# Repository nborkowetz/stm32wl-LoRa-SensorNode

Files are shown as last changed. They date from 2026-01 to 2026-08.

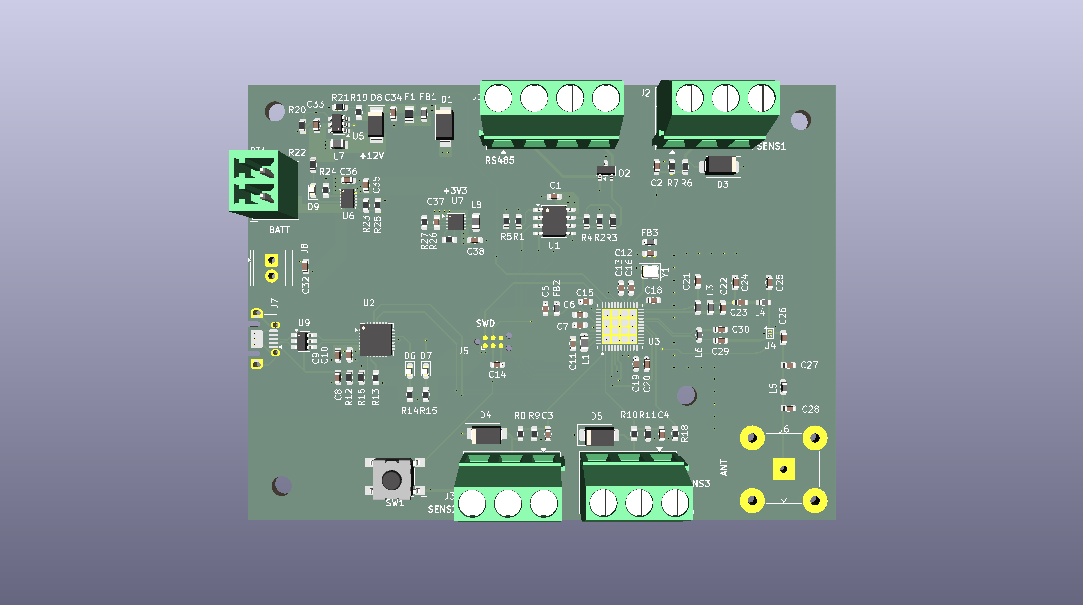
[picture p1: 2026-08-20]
Hardware/pcb/demo wateranalyser.png

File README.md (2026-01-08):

# STM32WL LoRaWAN Prototyping Platform
## Modular Sensor Node for Industrial IoT & Water Quality Monitoring

## 📌 Project Overview
This repository contains the hardware design for a high-performance, ultra-low-power LoRaWAN node based on the **STM32WL55CCU6** SoC. 

This platform serves as an **architectural evaluation board**. It is designed to validate power management strategies, RF performance, and modular sensor interfacing before final product miniaturization.

## 🛠 Technical Specifications

### Core System
* **MCU:** STM32WL55CCU6 (Dual-core ARM Cortex-M4/M0+).
* **Connectivity:** Sub-GHz radio supporting LoRa, (G)FSK, (G)MSK, and BPSK.
* **RF Path:** Optimized 868MHz output with an integrated **BGS12WN6** RF switch and pi-filter matching network.

### Power Management (Ultra-Low Power Focus)
The hardware implements a sophisticated power tree for extreme battery longevity:
* **TPS63900 Buck-Boost:** High-efficiency converter with ultra-low quiescent current, providing a stable 3.3V output across the entire battery discharge curve.
* **LiFePO4 Charging:** Integrated **BQ25071** linear charger, specifically optimized for the safety and cycle-life requirements of LiFePO4 chemistry.
* **Power Gating:** Dedicated load switches to fully disconnect sensor peripherals during deep-sleep cycles, minimizing leakage current.

### PCB Design & Signal Integrity
* **Layer Stack:** 4-layer design (Signal-GND-PWR-Signal) utilizing the **JLC04161H** stackup.
* **Impedance Control:** * **50Ω Single-Ended:** Precision routing for the RF signal path to the antenna.
  * **90Ω Differential:** Calculated for USB data integrity.
* **Manufacturing Ready:** The layout has successfully passed **DFM (Design for Manufacturing)** suites for industrial production standards.

## 🧪 Modular Sensing Interface
To act as a versatile testbed, the board includes:
* Multi-protocol headers (I2C, SPI, UART).
* Analog conditioning circuitry for environmental probes.
* ESD protection on all external sensor interface lines.

## 📂 Project Status
* **Hardware:** Design finalized and DFM-validated. Ready for prototyping.
* **Firmware:** Under active development. Implementing low-power routines and LoRaWAN stack integration using STM32CubeWL HAL.

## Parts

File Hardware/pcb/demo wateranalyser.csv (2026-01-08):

Id | Riferimento | Impronta | Quantità | Valore | Produttore
1 | FB3,FB2 | L_0603_1608Metric | 2 | 600Ohm@10MHz
2 | J1 | TerminalBlock_Phoenix_MKDS-1,5-4-5.08_1x04_P5.08mm_Horizontal | 1 | Screw_Terminal_01x04
3 | R23,R5,R20,R18,R10,R6,R1,R8 | R_0603_1608Metric | 8 | 10k
4 | L8 | L_0805_2012Metric | 1 | 2u2
5 | C32,C37 | C_0603_1608Metric | 2 | 10u
6 | C34,C38,C33 | C_0603_1608Metric | 3 | 22u
7 | R15,R22,R14 | R_0603_1608Metric | 3 | 750
8 | R24 | R_0603_1608Metric | 1 | 1k
9 | C6,C4,C10,C16,C19,C12,C7,C3,C1,C2,C18,C15,C8,C35,C36 | C_0603_1608Metric | 15 | 100n
10 | L7 | L_0805_2012Metric | 1 | 10u
11 | J3,J2,J4 | TerminalBlock_Phoenix_MKDS-1,5-3-5.08_1x03_P5.08mm_Horizontal | 3 | Screw_Terminal_01x03
12 | L1 | L_0805_2012Metric | 1 | 15u
13 | BT1 | PhoenixContact_MCV_1,5_2-G-3.81_1x02_P3.81mm_Vertical | 1 | Battery
14 | R27 | R_0603_1608Metric | 1 | 36k5
15 | D7,D6,D9 | LED_0603_1608Metric | 3 | LED
16 | C14,C13 | C_0603_1608Metric | 2 | 470n
17 | L3 | L_0603_1608Metric | 1 | 6n8
18 | R19 | R_0603_1608Metric | 1 | 41k7
19 | R13,R21 | R_0603_1608Metric | 2 | 2k2
20 | U4 | Infineon_PG-TSNP-6-10_0.7x1.1mm_0.7x1.1mm_P0.4mm | 1 | BGS12WN6E6327
21 | U2 | QFN-28-1EP_5x5mm_P0.5mm_EP3.35x3.35mm | 1 | CP2102N-Axx-xQFN28
22 | R7,R11,R26,R9 | R_0603_1608Metric | 4 | 16k2
23 | D2 | SOT-23 | 1 | SM712_SOT23
24 | D4,D3,D5 | D_SMA | 3 | SMAJ6.0CA
25 | U7 | WSON-10-1EP_2.5x2.5mm_P0.5mm_EP1.2x2mm_ThermalVias | 1 | TPS63900
26 | SW1 | SW_SPST_Omron_B3FS-100xP | 1 | SW_Omron_B3FS
27 | J7 | USB_Micro-AB_Molex_47590-0001 | 1 | USB_B_Micro
28 | R2,R3 | R_0603_1608Metric | 2 | 10
29 | FB1 | L_0603_1608Metric | 1 | 220Ohm @ 100MHz
30 | U5 | SOT-23-6 | 1 | MT3608
31 | C24 | C_0603_1608Metric | 1 | 15p
32 | C11,C20,C9,C5 | C_0603_1608Metric | 4 | 4u7
33 | L2 | L_0603_1608Metric | 1 | 56n
34 | F1 | Fuse_0805_2012Metric | 1 | 200mA
35 | U9 | SOT-23-6_Handsoldering | 1 | WE-TVS-82400102
36 | R4 | R_0603_1608Metric | 1 | 120
37 | C25 | C_0603_1608Metric | 1 | 5p6
38 | C30 | C_0603_1608Metric | 1 | 4p7
39 | L6 | L_0603_1608Metric | 1 | 33n
40 | C26,C23,C21 | C_0603_1608Metric | 3 | 68p
41 | J8 | TerminalBlock_TE_282834-2_1x02_P2.54mm_Horizontal | 1 | Conn_01x02
42 | R12 | R_0603_1608Metric | 1 | 22k1
43 | L4,L5 | L_0603_1608Metric | 2 | 16n
44 | C28,C27 | C_0603_1608Metric | 2 | 6p8
45 | U3 | QFN-48-1EP_7x7mm_P0.5mm_EP5.6x5.6mm | 1 | STM32WL55CCUx
46 | Y1 | Oscillator_SMD_SeikoEpson_SG210-4Pin_2.5x2.0mm | 1 | SG-210STF 32MHz
47 | U1 | SOIC-8_3.9x4.9mm_P1.27mm | 1 | THVD1400D
48 | U6 | WSON-10-1EP_2x3mm_P0.5mm_EP0.84x2.4mm_ThermalVias | 1 | BQ25071
49 | R16 | R_0603_1608Metric | 1 | 47k5
50 | J6 | BNC_TEConnectivity_1478035_Horizontal | 1 | Conn_Coaxial
51 | R25 | R_0603_1608Metric | 1 | 49k
52 | D1 | D_SMA | 1 | SMAJ12CA
53 | C29 | C_0603_1608Metric | 1 | 3p6
54 | C22 | C_0603_1608Metric | 1 | 4p3
55 | D8 | D_SOD-128 | 1 | SB120

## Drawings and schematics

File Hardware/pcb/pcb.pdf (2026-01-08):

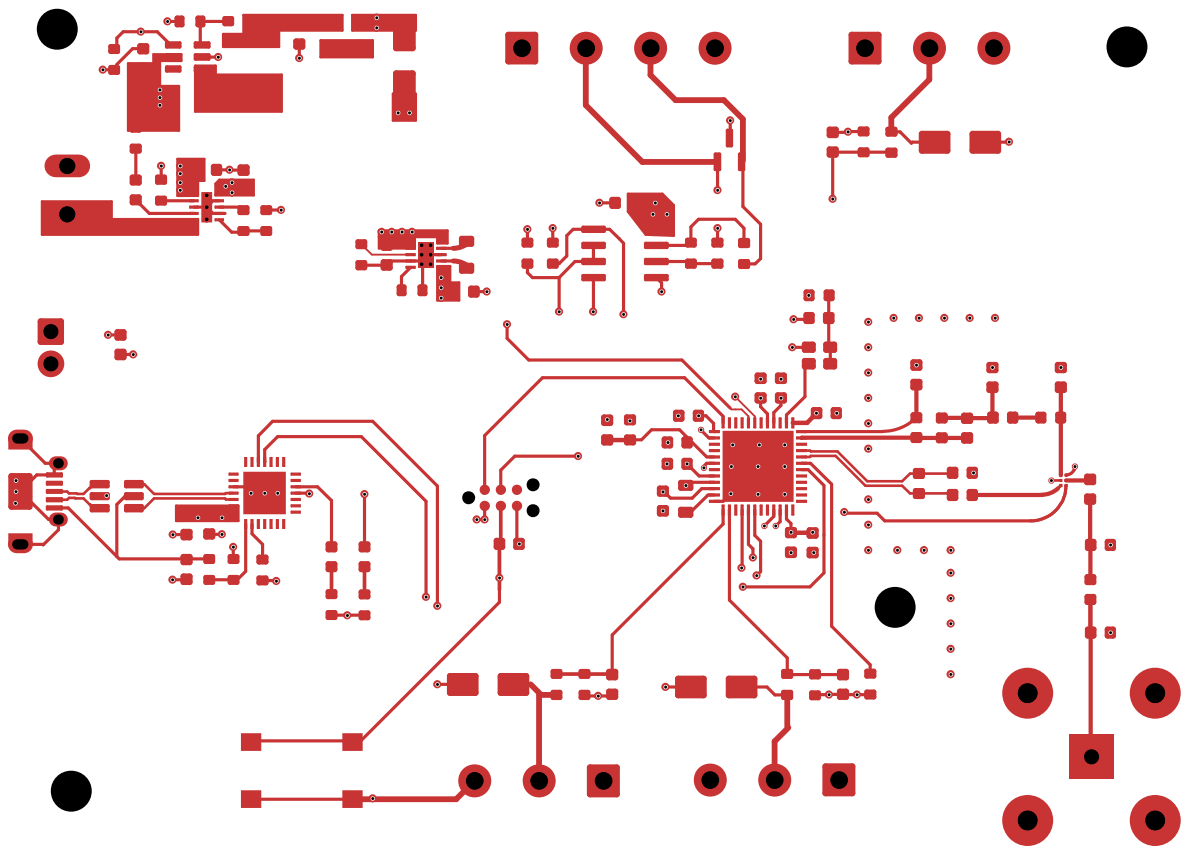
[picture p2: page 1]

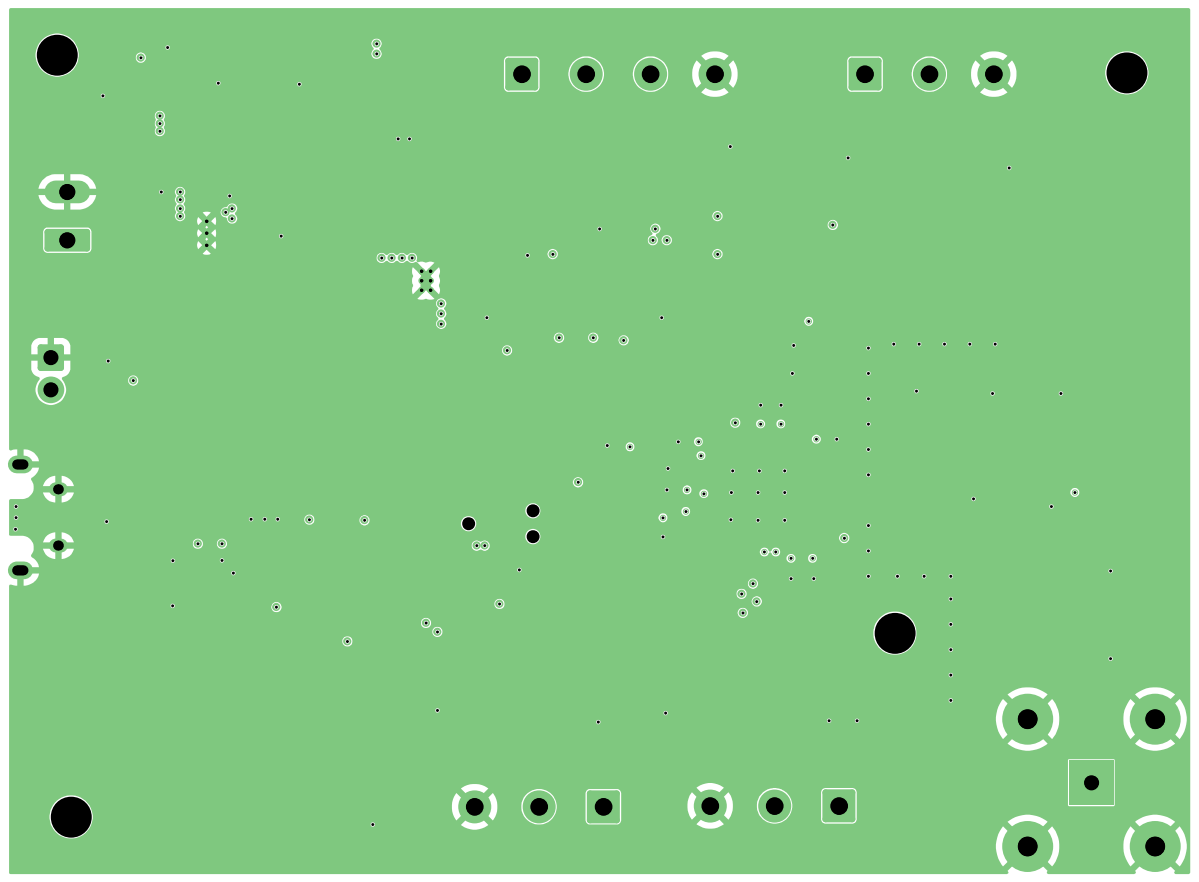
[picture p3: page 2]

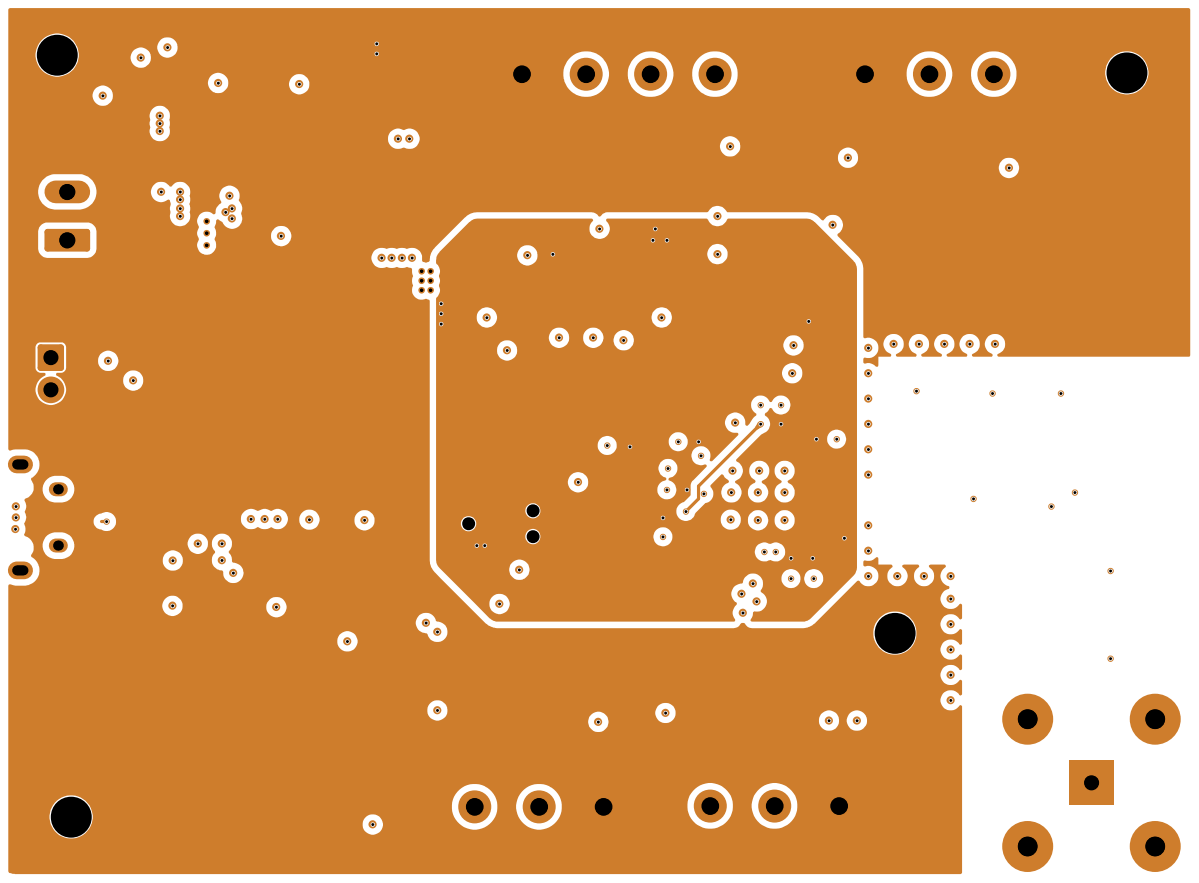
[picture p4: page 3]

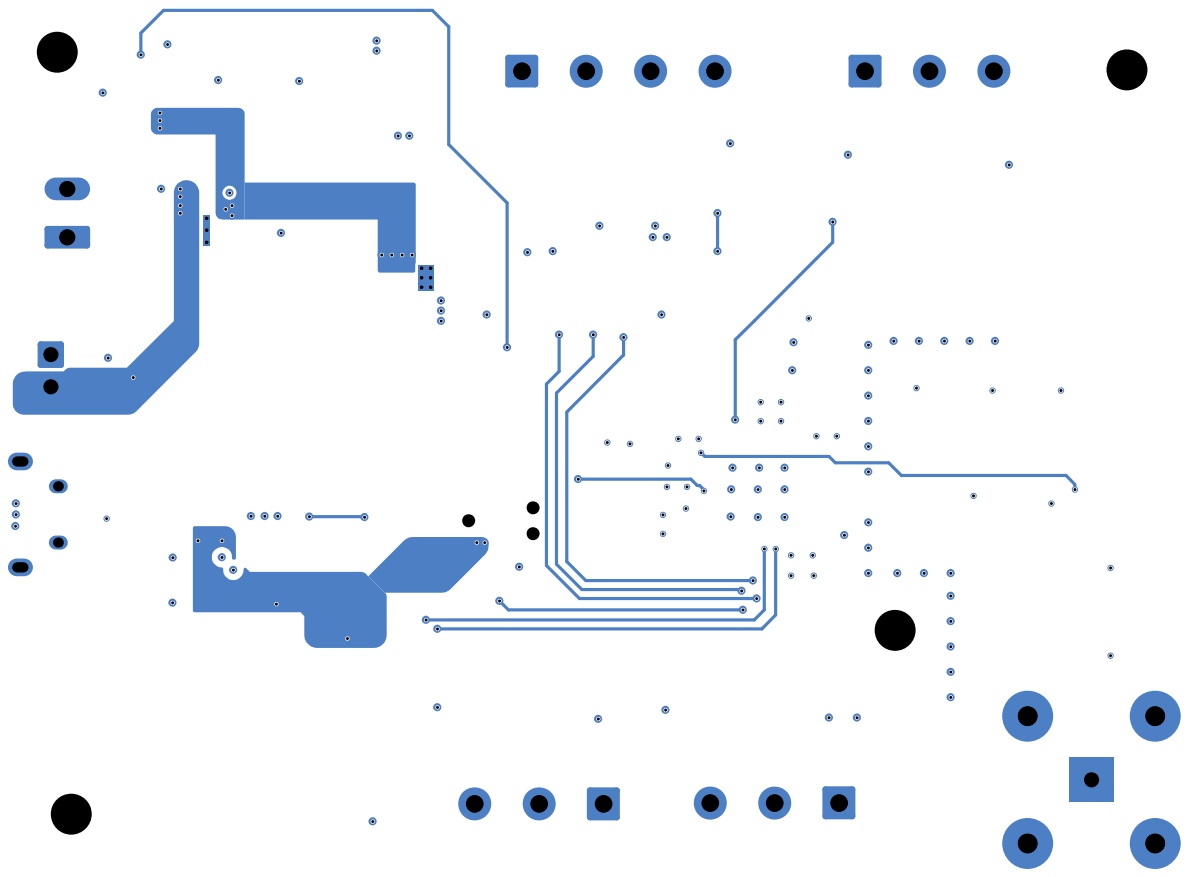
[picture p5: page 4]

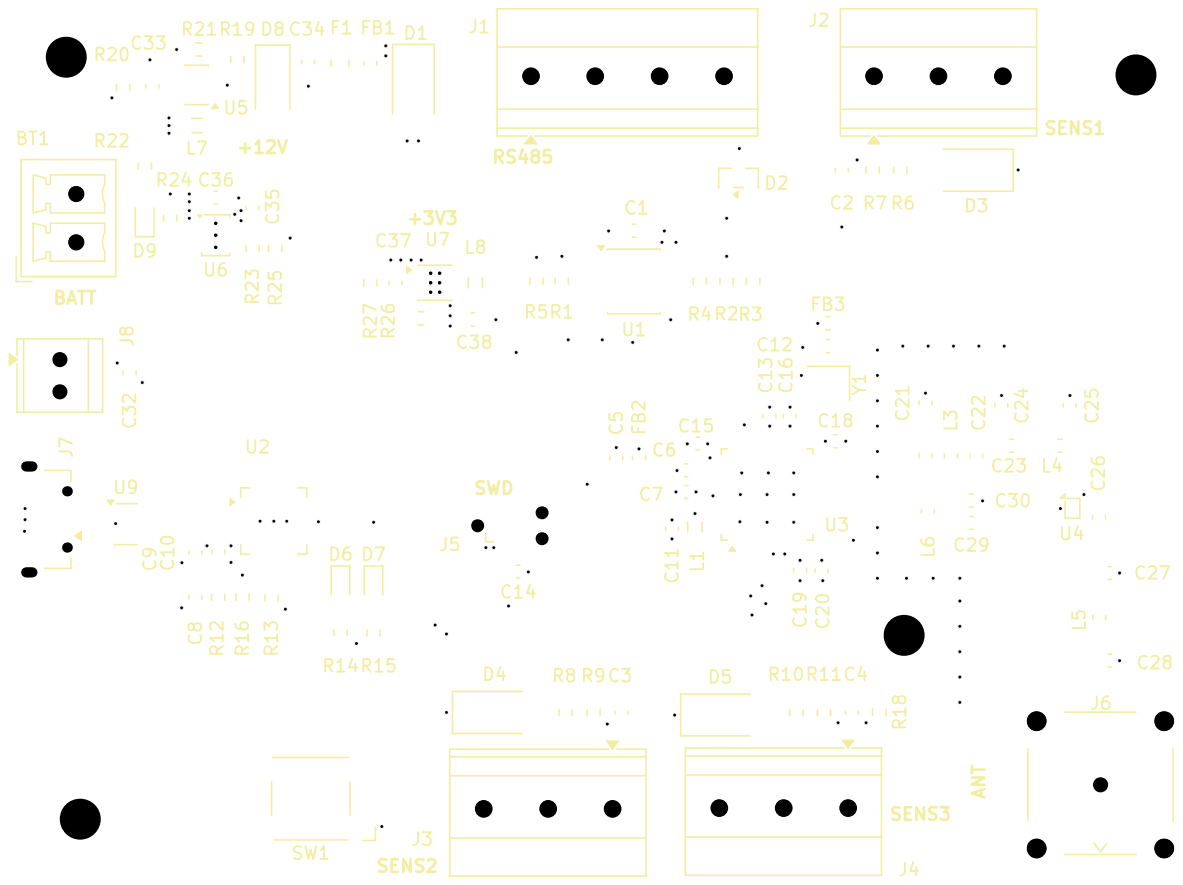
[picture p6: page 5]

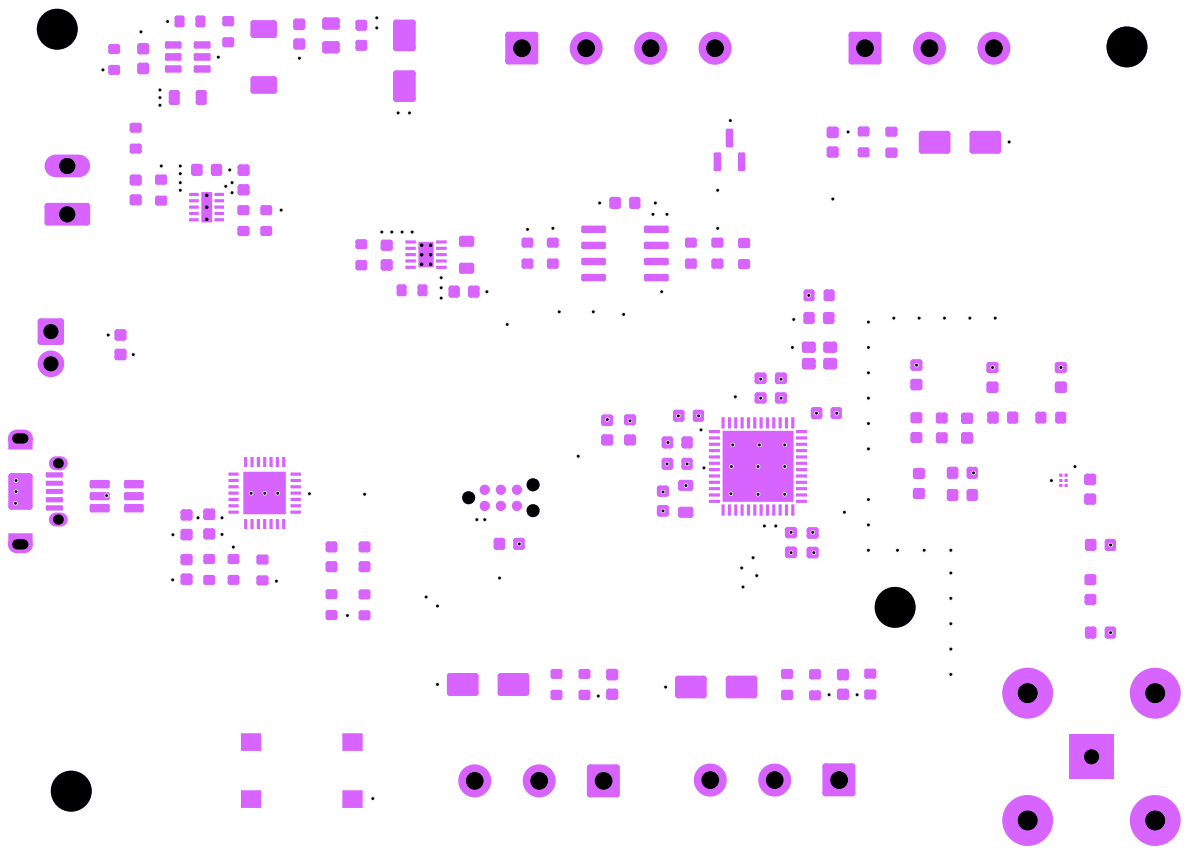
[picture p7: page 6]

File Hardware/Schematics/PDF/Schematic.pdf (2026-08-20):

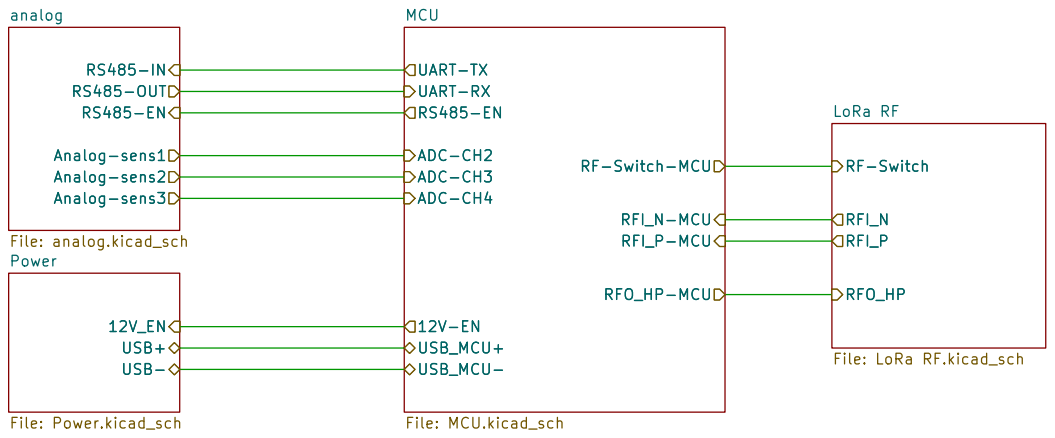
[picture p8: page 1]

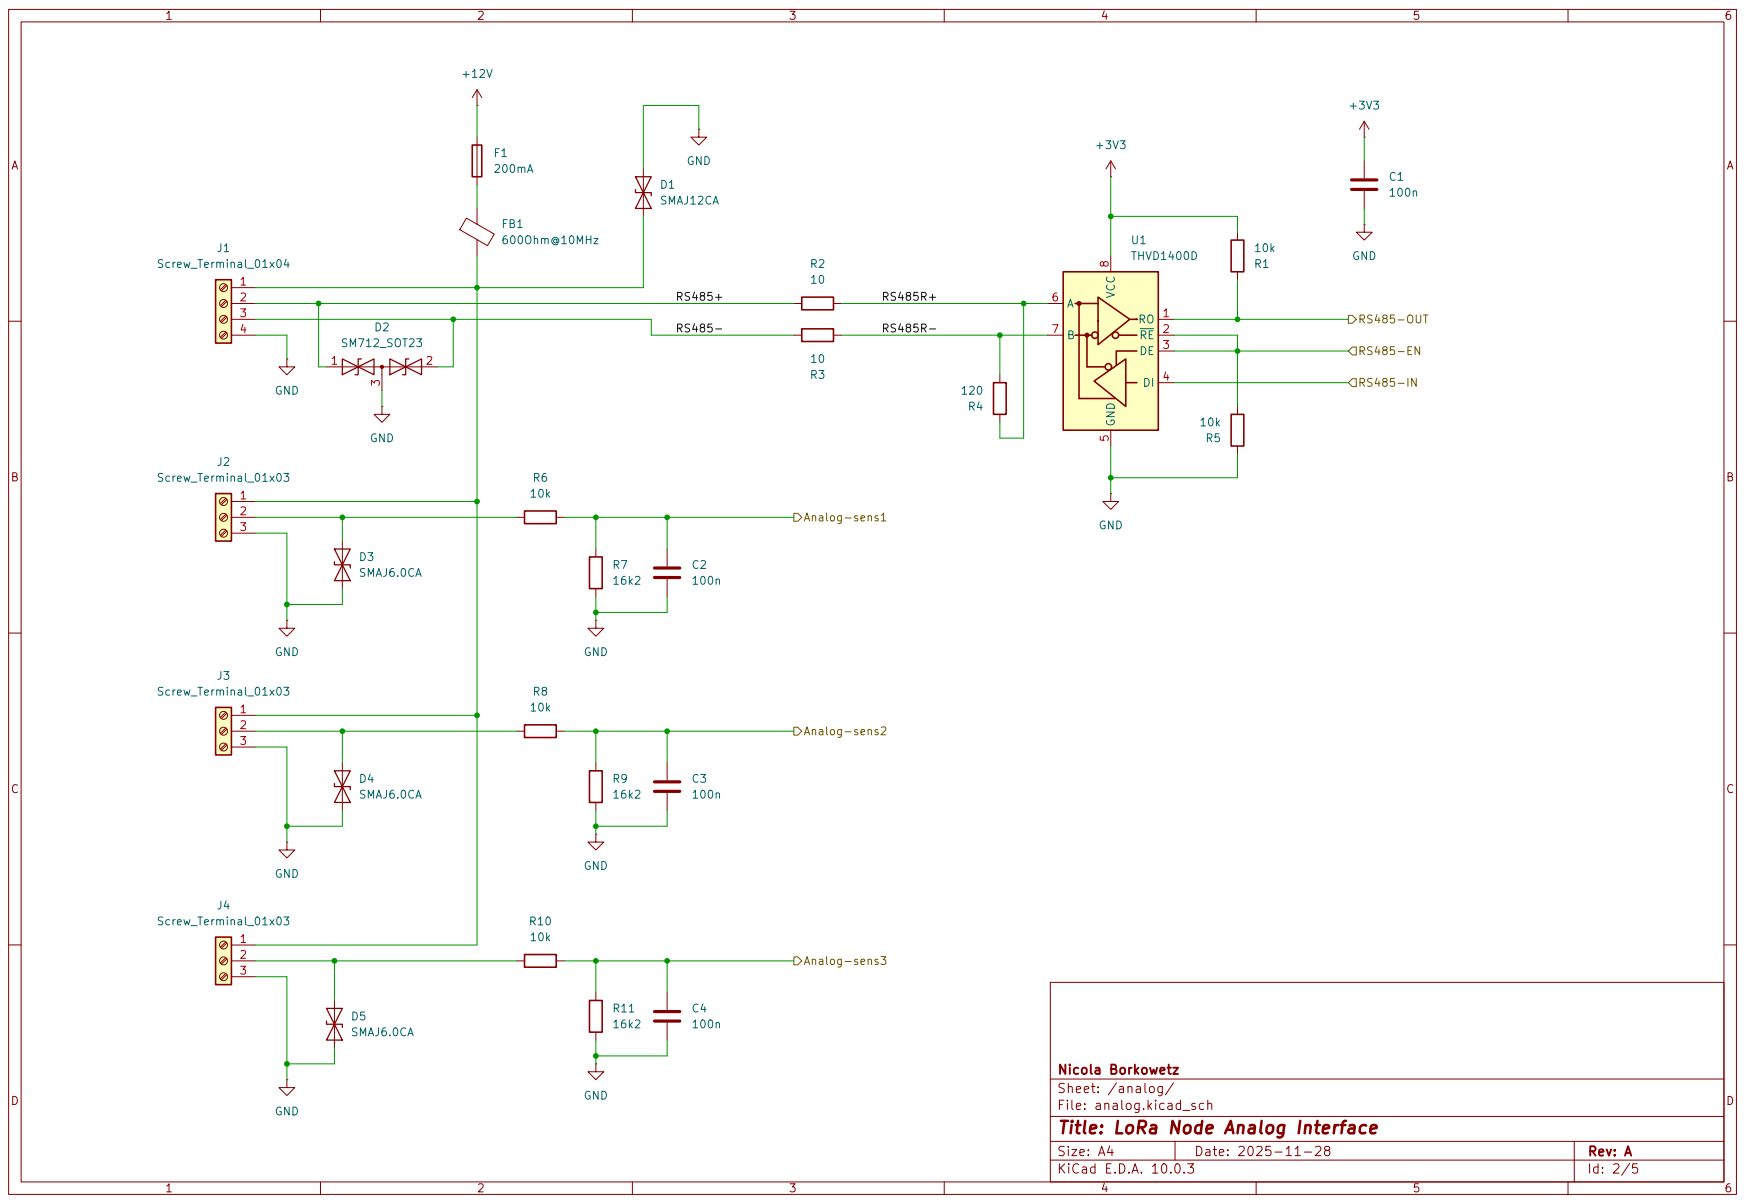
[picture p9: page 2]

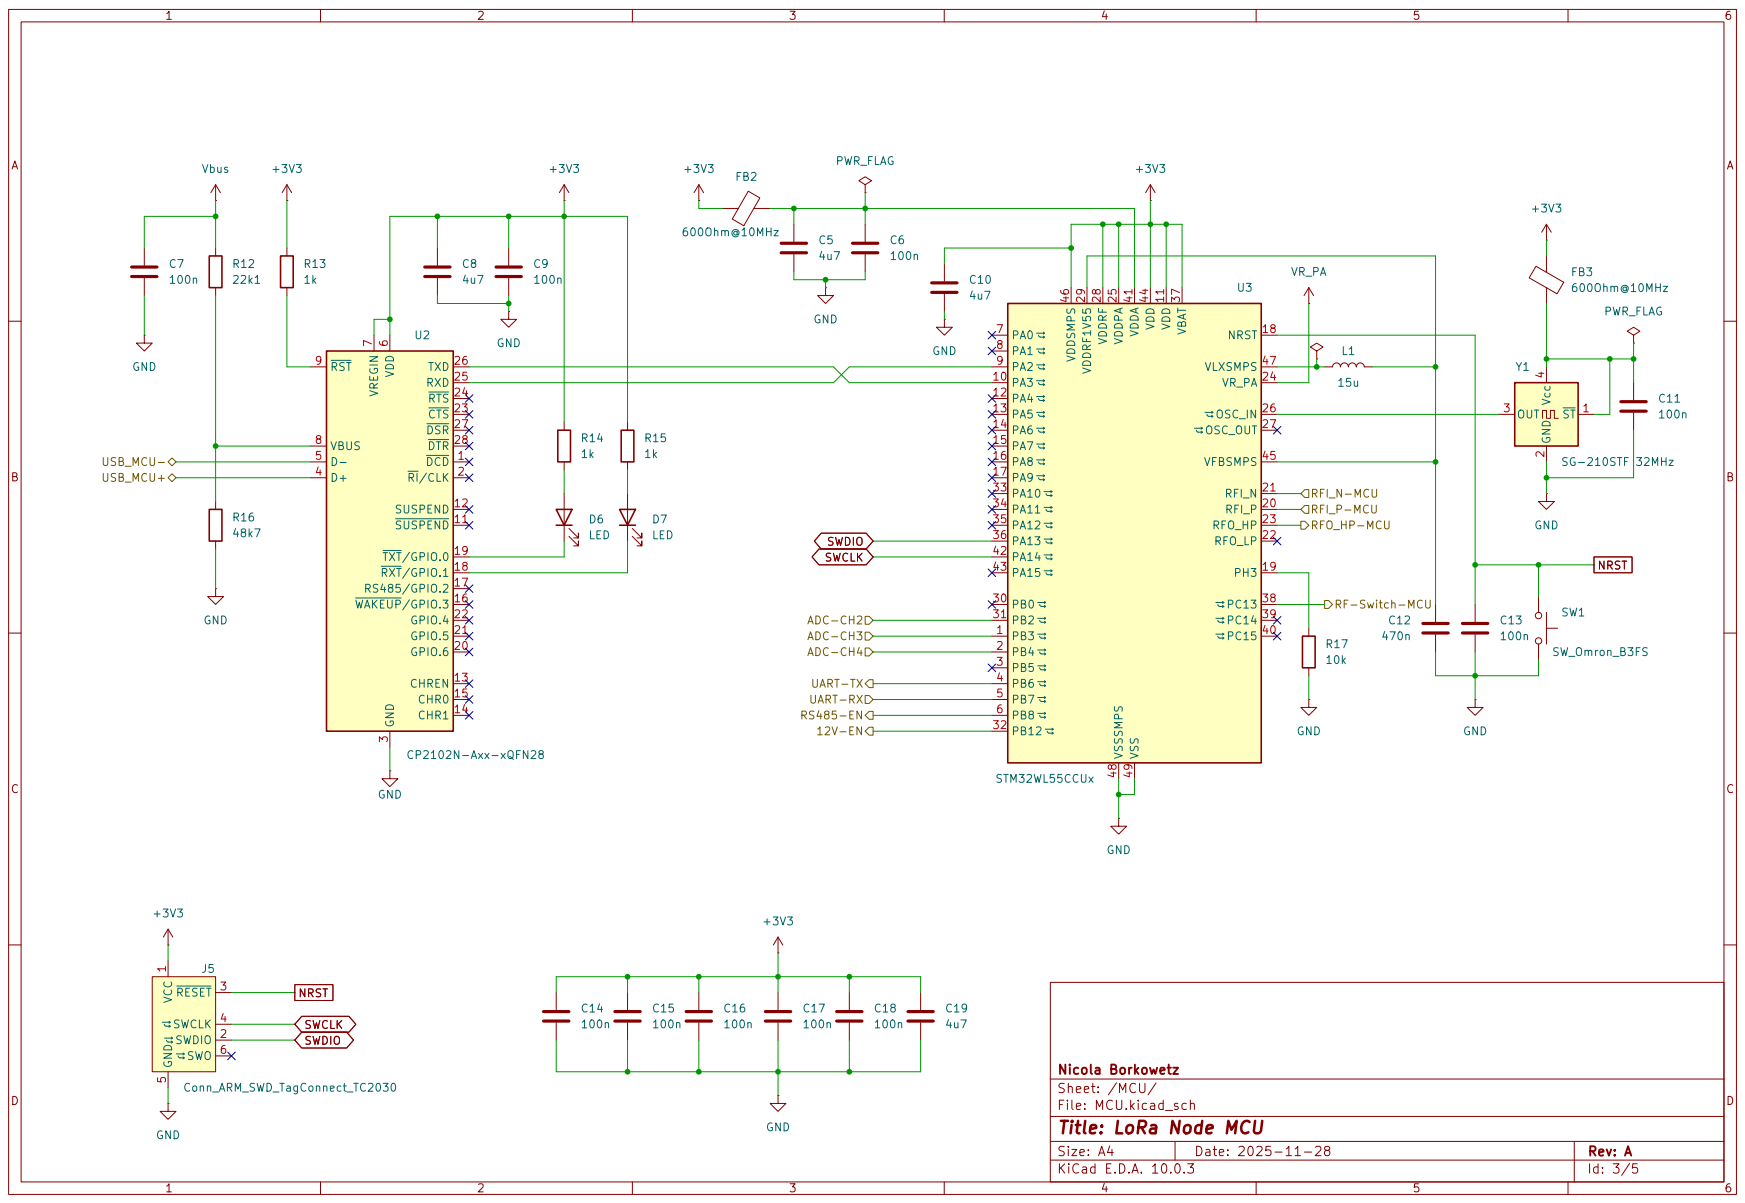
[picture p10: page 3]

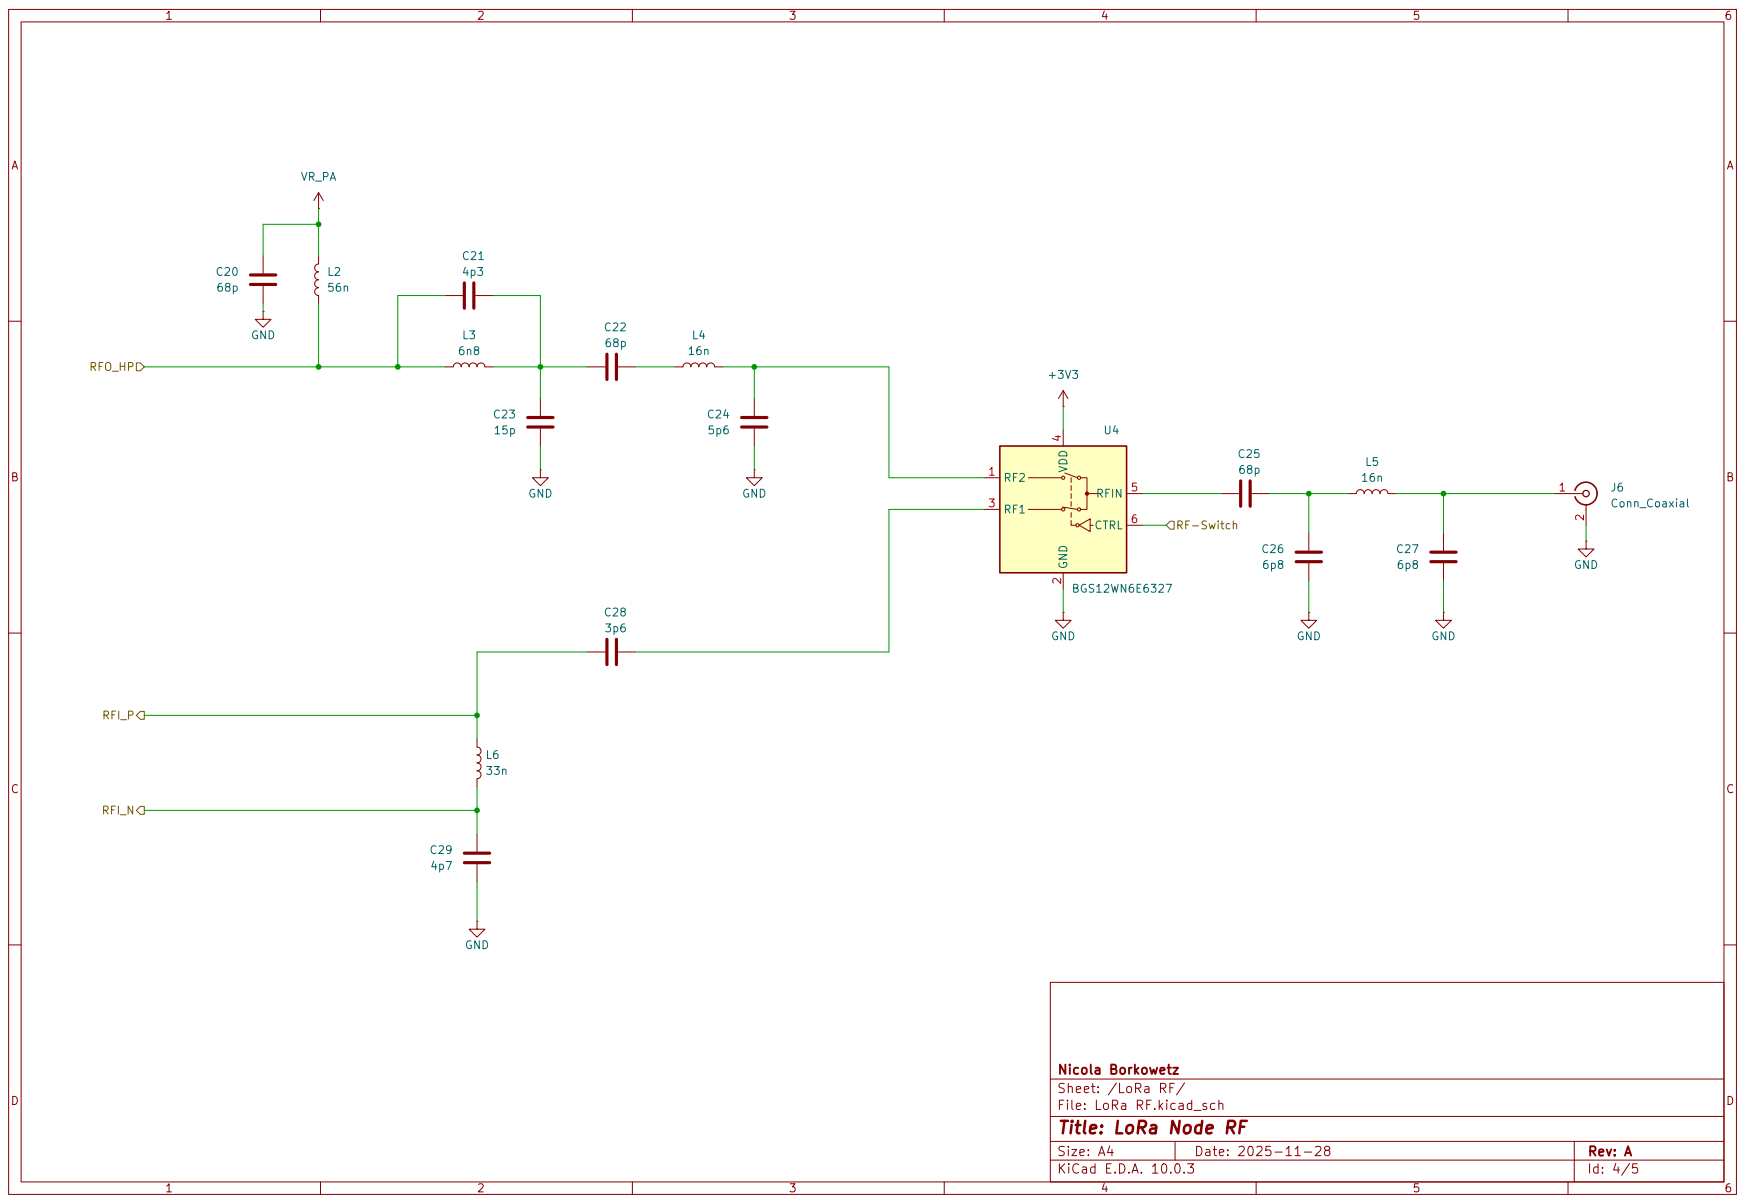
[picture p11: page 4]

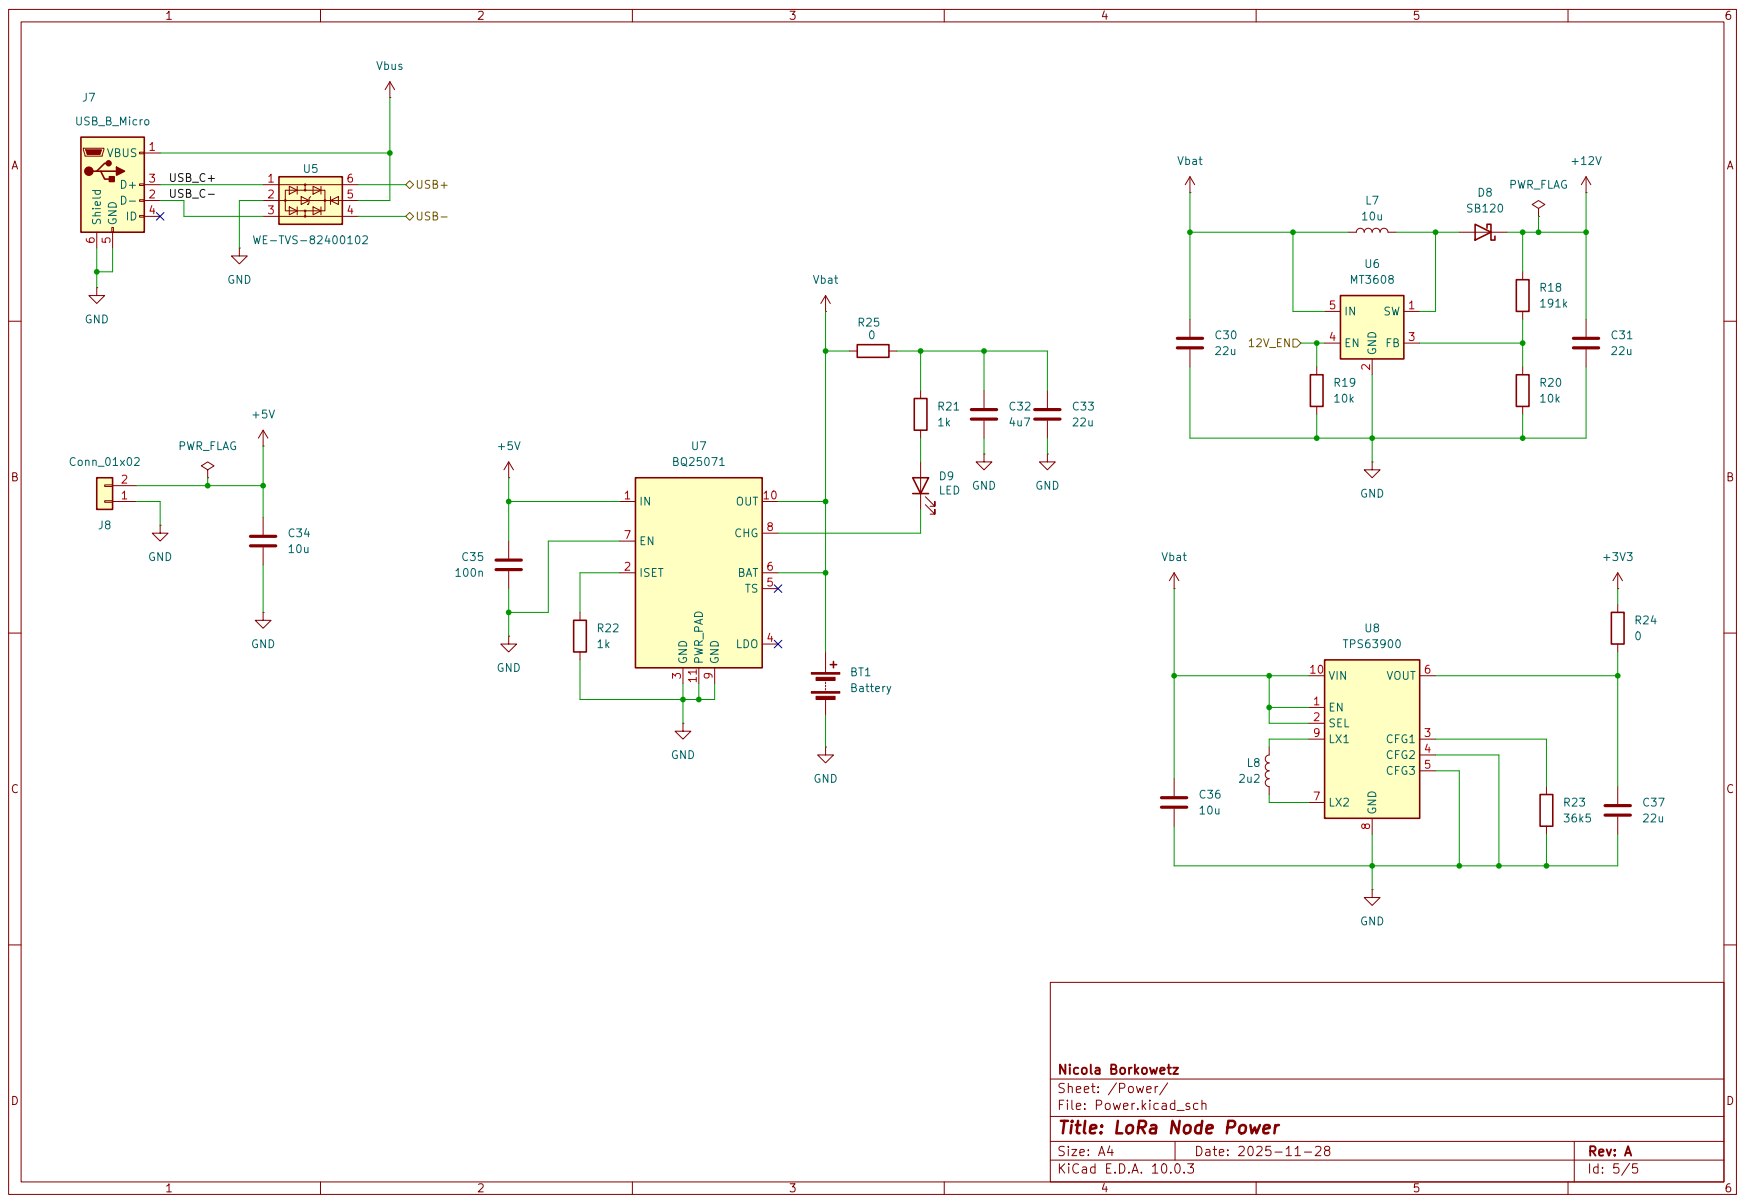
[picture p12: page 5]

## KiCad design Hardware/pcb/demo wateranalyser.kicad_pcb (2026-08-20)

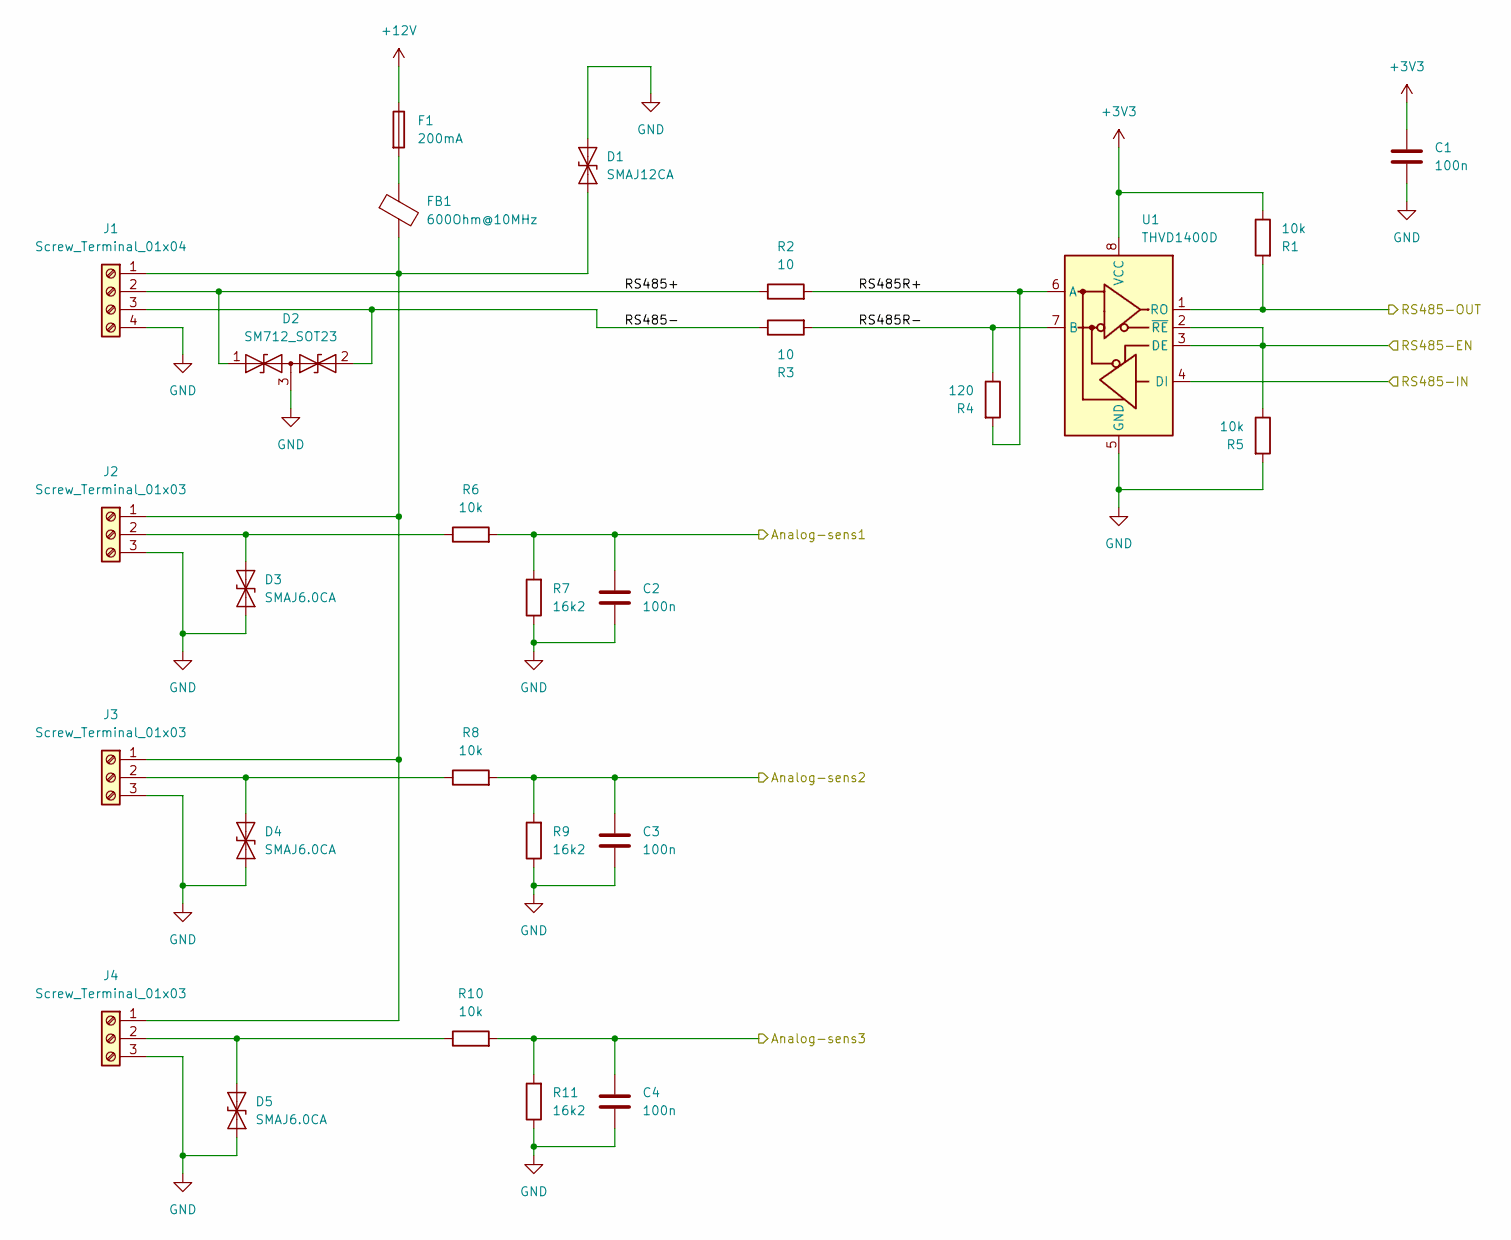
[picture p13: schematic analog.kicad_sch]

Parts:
C1, C2, C3, C4: 100n; C_0603_1608Metric
D1: SMAJ12CA; D_SMA
D2: SM712_SOT23; SOT-23
D3, D4, D5: SMAJ6.0CA; D_SMA
F1: 200mA; Fuse_0805_2012Metric
FB1: 600Ohm@10MHz; L_0603_1608Metric
J1: Screw_Terminal_01x04; TerminalBlock_Phoenix_MKDS-1,5-4-5.08_1x04_P5.08mm_Horizont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
J2, J3, J4: Screw_Terminal_01x03; TerminalBlock_Phoenix_MKDS-1,5-3-5.08_1x03_P5.08mm_Horizont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
R1, R5, R6, R8, R10: 10k; R_0603_1608Metric
R2, R3: 10; R_0603_1608Metric
R4: 120; R_0603_1608Metric
R7, R9, R11: 16k2; R_0603_1608Metric
U1: THVD1400D; SOIC-8_3.9x4.9mm_P1.27mm

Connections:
+3V3: C1.1, R1.1, U1.8 (VCC); also elsewhere on the board
+12V: F1.1; also elsewhere on the board
/MCU/ADC-CH2: C2.1, R6.2, R7.2; also elsewhere on the board
/MCU/ADC-CH3: C3.1, R8.2, R9.2; also elsewhere on the board
/MCU/ADC-CH4: C4.1, R10.2, R11.2; also elsewhere on the board
/MCU/RS485-EN: R5.1, U1.2 (~RE), U1.3 (DE); also elsewhere on the board
/MCU/UART-RX: R1.2, U1.1 (RO); also elsewhere on the board
/MCU/UART-TX: U1.4 (DI); also elsewhere on the board
/analog/RS485+: D2.1 (A1), J1.2, R2.1
/analog/RS485-: D2.2 (A2), J1.3, R3.1
/analog/RS485R+: R2.2, R4.2, U1.6 (A)
/analog/RS485R-: R3.2, R4.1, U1.7 (B)
unnamed: D1.1 (A1), FB1.2, J1.1, J2.1, J3.1, J4.1
unnamed: D3.2 (A2), J2.2, R6.1
unnamed: D4.2 (A2), J3.2, R8.1
unnamed: D5.2 (A2), J4.2, R10.1
unnamed: F1.2, FB1.1

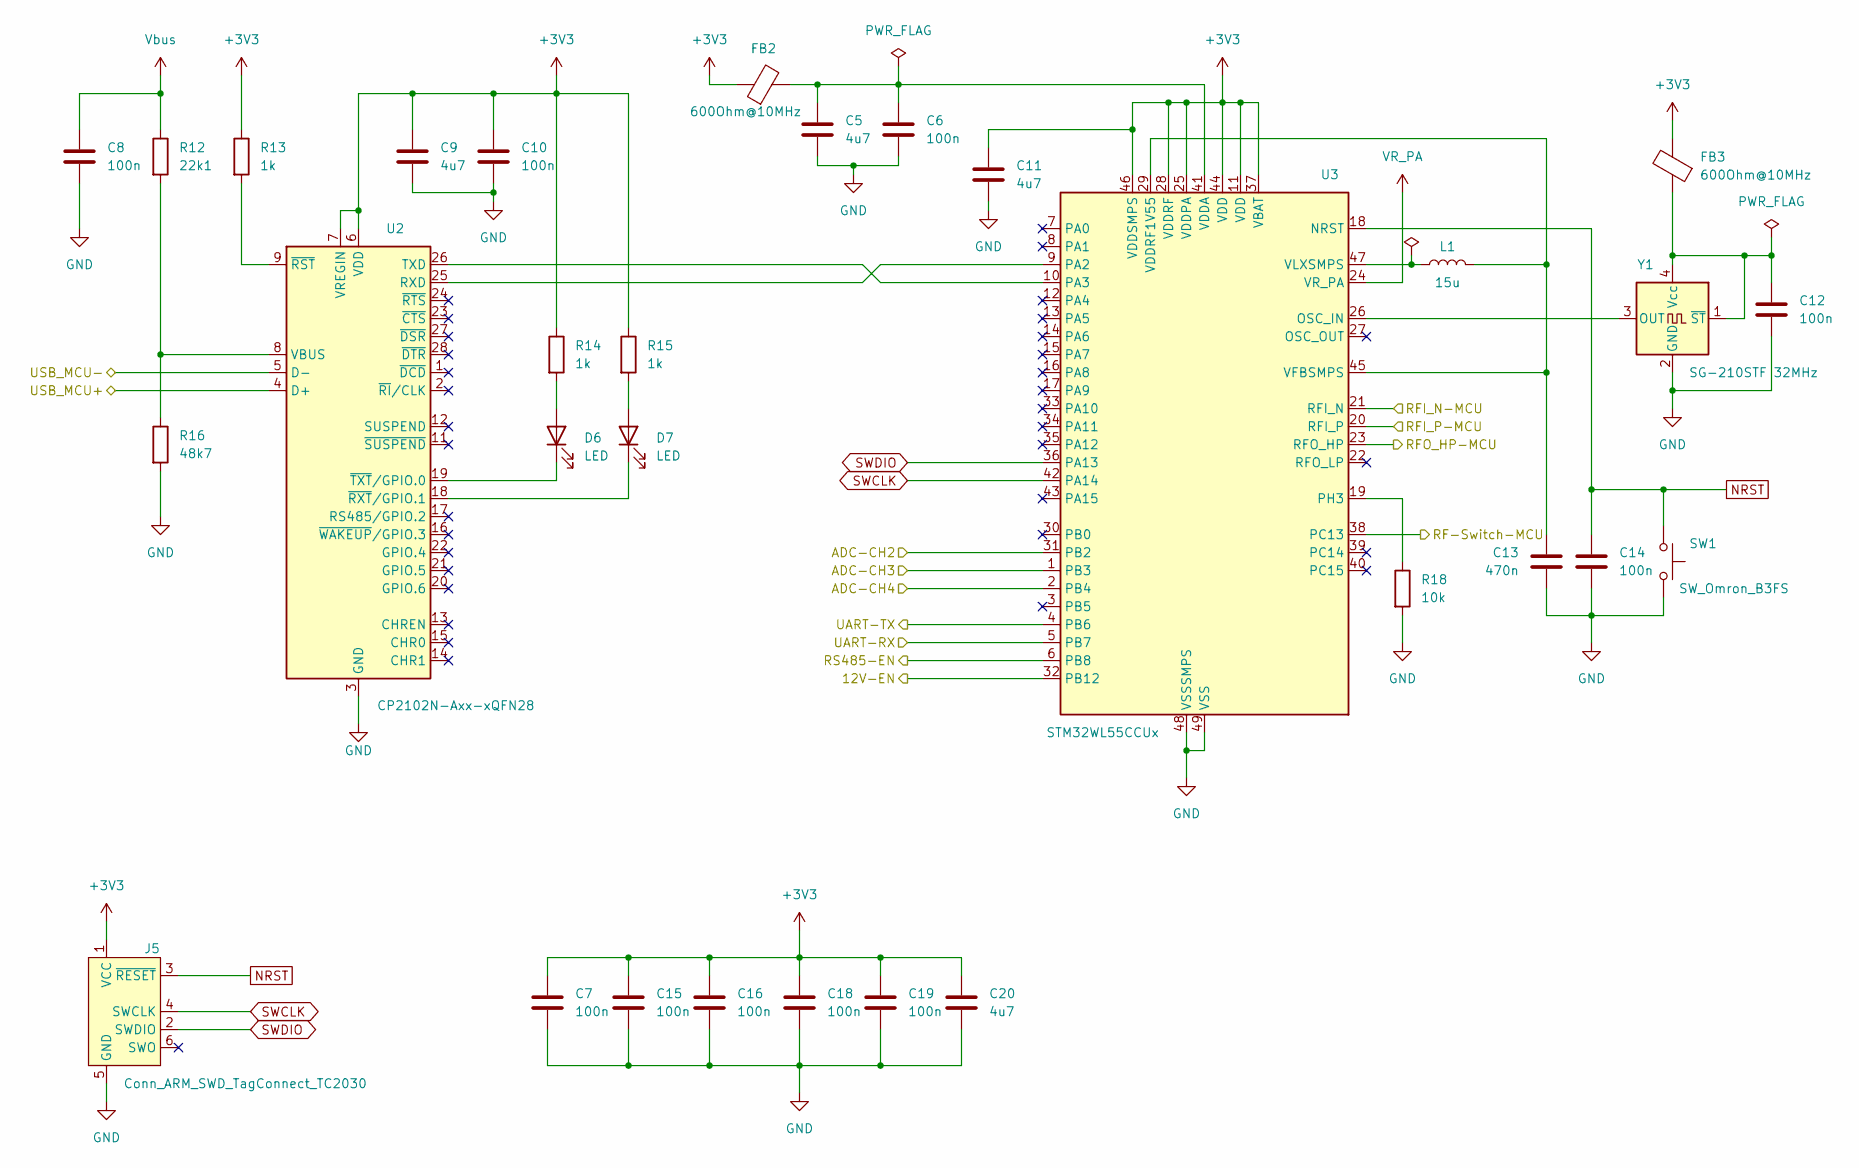
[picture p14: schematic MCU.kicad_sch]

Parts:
C5, C9, C11, C20: 4u7; C_0603_1608Metric
C6, C7, C8, C10, C12, C14, C15, C16, C18, C19: 100n; C_0603_1608Metric
C13: 470n; C_0603_1608Metric
D6, D7: LED; LED_0603_1608Metric
FB2, FB3: 600Ohm@10MHz; L_0603_1608Metric
J5: Conn_ARM_SWD_TagConnect_TC2030; Tag-Connect_TC2030-IDC-NL_2x03_P1.27mm_Vertical
L1: 15u; L_0805_2012Metric
R12: 22k1; R_0603_1608Metric
R13, R14, R15: 1k; R_0603_1608Metric
R16: 48k7; R_0603_1608Metric
R18: 10k; R_0603_1608Metric
SW1: SW_Omron_B3FS; SW_SPST_Omron_B3FS-100xP
U2: CP2102N-Axx-xQFN28; QFN-28-1EP_5x5mm_P0.5mm_EP3.35x3.35mm
U3: STM32WL55CCUx; QFN-48-1EP_7x7mm_P0.5mm_EP5.6x5.6mm
Y1: SG-210STF 32MHz; Oscillator_SMD_SeikoEpson_SG210-4Pin_2.5x2.0mm

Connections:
+3V3: C7.1, C9.1, C10.1, C11.1, C15.1, C16.1, C18.1, C19.1, C20.1, FB2.1, FB3.2, J5.1 (VCC), R13.1, R14.1, R15.1, U2.6 (VDD), U2.7 (VREGIN), U3.11 (VDD), U3.25 (VDDPA), U3.28 (VDDRF), U3.37 (VBAT), U3.44 (VDD), U3.46 (VDDSMPS); also elsewhere on the board
/LoRa RF/RF-Switch: U3.38 (PC13); also elsewhere on the board
/LoRa RF/RFI_N: U3.21 (RFI_N); also elsewhere on the board
/LoRa RF/RFI_P: U3.20 (RFI_P); also elsewhere on the board
/LoRa RF/RFO_HP: U3.23 (RFO_HP); also elsewhere on the board
/MCU/12V-EN: U3.32 (PB12); also elsewhere on the board
/MCU/ADC-CH2: U3.31 (PB2); also elsewhere on the board
/MCU/ADC-CH3: U3.1 (PB3); also elsewhere on the board
/MCU/ADC-CH4: U3.2 (PB4); also elsewhere on the board
/MCU/RS485-EN: U3.6 (PB8); also elsewhere on the board
/MCU/UART-RX: U3.5 (PB7); also elsewhere on the board
/MCU/UART-TX: U3.4 (PB6); also elsewhere on the board
/MCU/USB_MCU+: U2.4 (D+); also elsewhere on the board
/MCU/USB_MCU-: U2.5 (D-); also elsewhere on the board
NRST: C14.1, J5.3 (~RESET), SW1.2, U3.18 (NRST)
unnamed: D6.2 (A), R14.2
unnamed: D6.1 (K), U2.19 (~TXT/GPIO.0)
unnamed: D7.2 (A), R15.2
unnamed: D7.1 (K), U2.18 (~RXT/GPIO.1)
unnamed: U2.25 (RXD), U3.9 (PA2)
unnamed: U2.26 (TXD), U3.10 (PA3)
unnamed: R12.2, R16.1, U2.8 (VBUS)
unnamed: R13.2, U2.9 (~RST)
unnamed: U3.26 (OSC_IN), Y1.3 (OUT)
unnamed: R18.1, U3.19 (PH3)
unnamed: C5.1, C6.1, FB2.2, U3.41 (VDDA)
unnamed: C13.1, L1.2, U3.29 (VDDRF1V55), U3.45 (VFBSMPS)
unnamed: L1.1, U3.47 (VLXSMPS)
unnamed: C12.1, FB3.1, Y1.1 (~ST), Y1.4 (Vcc)
SWCLK: J5.4 (SWCLK), U3.42 (PA14)
SWDIO: J5.2 (SWDIO), U3.36 (PA13)
VR_PA: U3.24 (VR_PA); also elsewhere on the board
Vbus: C8.1, R12.1; also elsewhere on the board

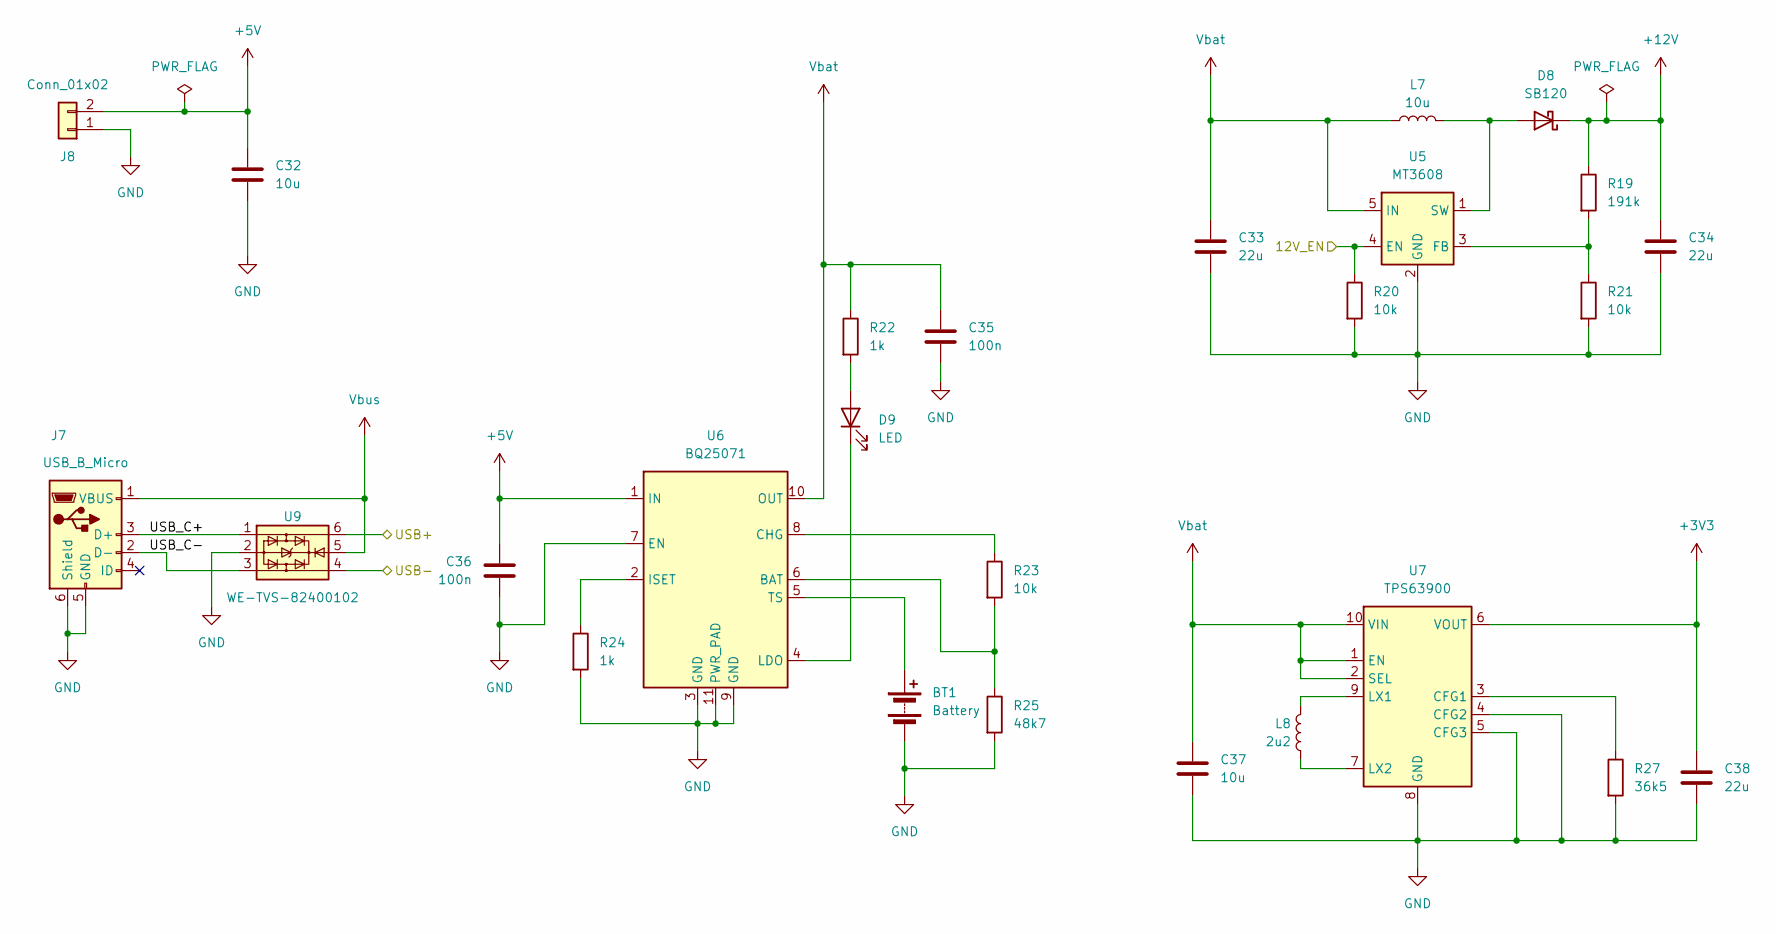
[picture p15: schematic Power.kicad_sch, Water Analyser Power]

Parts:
BT1: Battery; PhoenixContact_MCV_1,5_2-G-3.81_1x02_P3.81mm_Vertical
C32, C37: 10u; C_0603_1608Metric
C33, C34, C38: 22u; C_0603_1608Metric
C35, C36: 100n; C_0603_1608Metric
D8: SB120; D_SOD-128
D9: LED; LED_0603_1608Metric
J7: USB_B_Micro; USB_Micro-AB_Molex_47590-0001
J8: Conn_01x02; TerminalBlock_TE_282834-2_1x02_P2.54mm_Horizontal
L7: 10u; L_0805_2012Metric
L8: 2u2; L_0805_2012Metric
R19: 191k; R_0603_1608Metric
R20, R21, R23: 10k; R_0603_1608Metric
R22, R24: 1k; R_0603_1608Metric
R25: 48k7; R_0603_1608Metric
R27: 36k5; R_0603_1608Metric
U5: MT3608; SOT-23-6
U6: BQ25071; WSON-10-1EP_2x3mm_P0.5mm_EP0.84x2.4mm_ThermalVias
U7: TPS63900; WSON-10-1EP_2.5x2.5mm_P0.5mm_EP1.2x2mm_ThermalVias
U9: WE-TVS-82400102; SOT-23-6_Handsoldering

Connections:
+3V3: C38.1, U7.6 (VOUT); also elsewhere on the board
+5V: C32.1, C36.1, J8.2, U6.1 (IN)
+12V: C34.1, D8.1 (K), R19.1; also elsewhere on the board
/MCU/12V-EN: R20.1, U5.4 (EN); also elsewhere on the board
/MCU/USB_MCU+: U9.6; also elsewhere on the board
/MCU/USB_MCU-: U9.4; also elsewhere on the board
/Power/USB_C+: J7.3 (D+), U9.1
/Power/USB_C-: J7.2 (D-), U9.3
unnamed: BT1.1 (+), U6.5 (TS)
unnamed: D8.2 (A), L7.2, U5.1 (SW)
unnamed: D9.2 (A), R22.2
unnamed: D9.1 (K), U6.4 (LDO)
unnamed: R19.2, R21.1, U5.3 (FB)
unnamed: R23.2, R25.1, U6.6 (BAT)
unnamed: R23.1, U6.8 (CHG)
unnamed: R24.1, U6.2 (ISET)
unnamed: R27.1, U7.3 (CFG1)
unnamed: L8.1, U7.9 (LX1)
unnamed: L8.2, U7.7 (LX2)
Vbat: C33.1, C35.1, C37.1, L7.1, R22.1, U5.5 (IN), U6.10 (OUT), U7.1 (EN), U7.2 (SEL), U7.10 (VIN)
Vbus: J7.1 (VBUS), U9.5; also elsewhere on the board

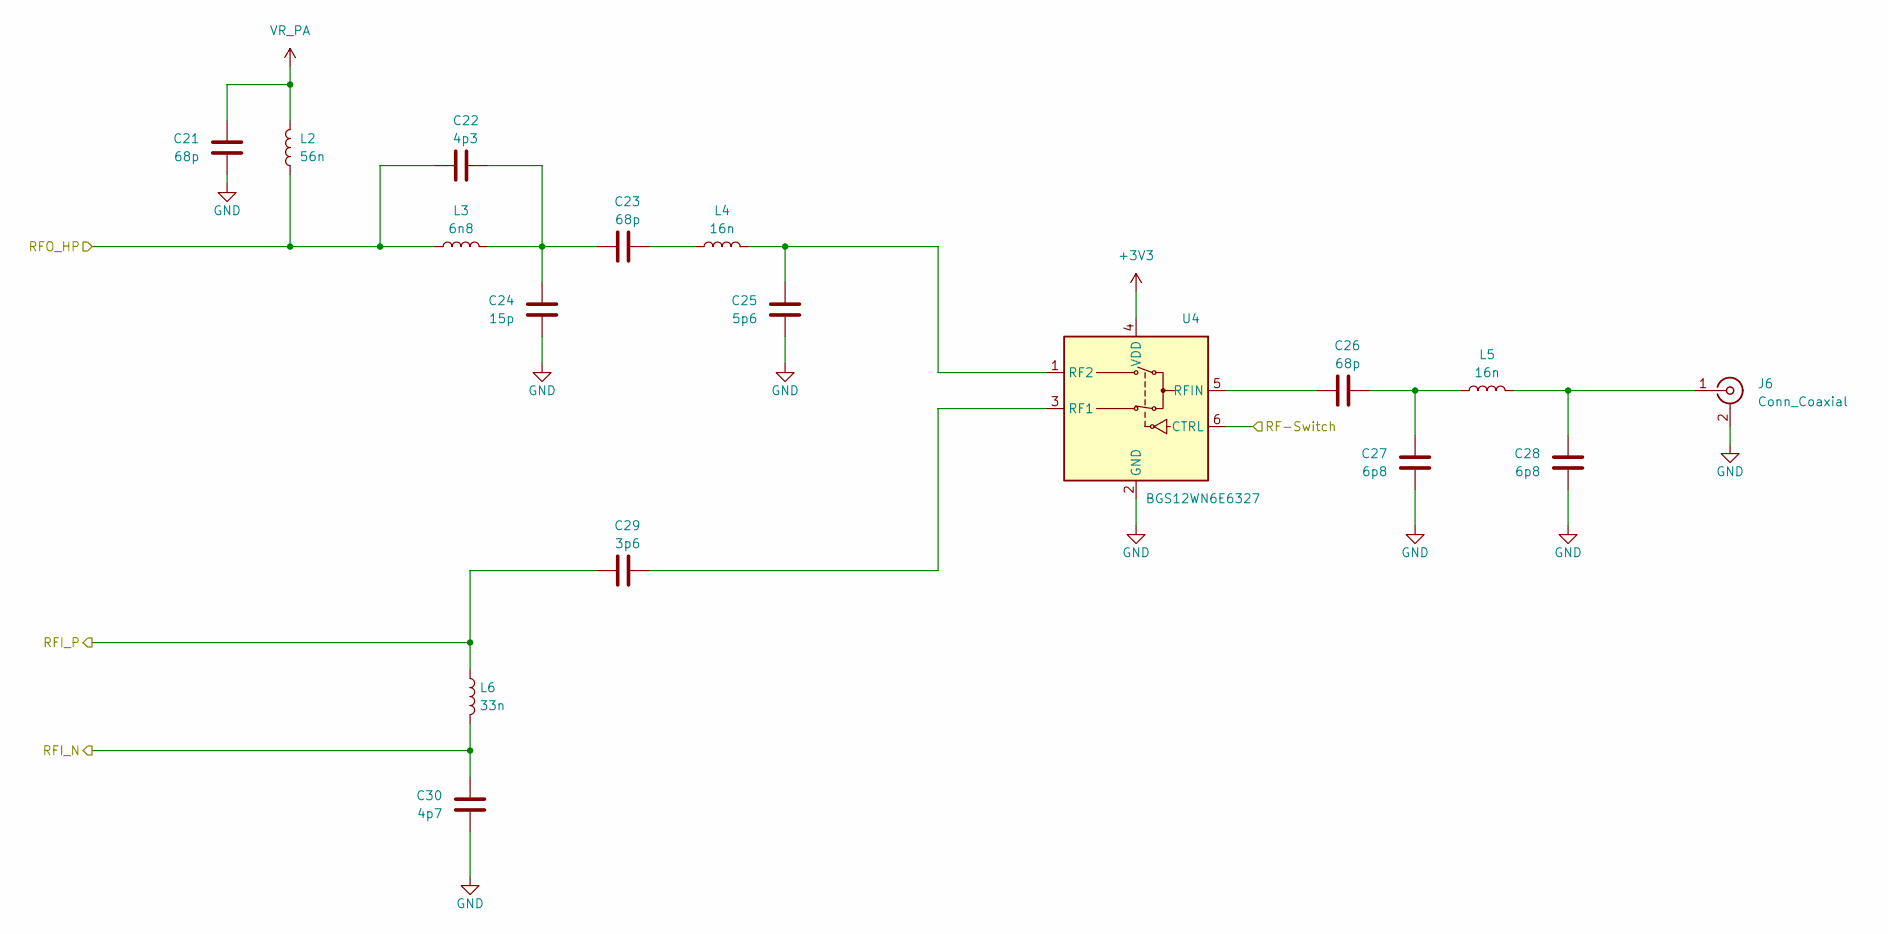
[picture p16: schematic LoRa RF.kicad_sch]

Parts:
C21, C23, C26: 68p; C_0603_1608Metric
C22: 4p3; C_0603_1608Metric
C24: 15p; C_0603_1608Metric
C25: 5p6; C_0603_1608Metric
C27, C28: 6p8; C_0603_1608Metric
C29: 3p6; C_0603_1608Metric
C30: 4p7; C_0603_1608Metric
J6: Conn_Coaxial; BNC_TEConnectivity_1478035_Horizontal
L2: 56n; L_0603_1608Metric
L3: 6n8; L_0603_1608Metric
L4, L5: 16n; L_0603_1608Metric
L6: 33n; L_0603_1608Metric
U4: BGS12WN6E6327; Infineon_PG-TSNP-6-10_0.7x1.1mm_0.7x1.1mm_P0.4mm

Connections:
+3V3: U4.4 (VDD); also elsewhere on the board
/LoRa RF/RF-Switch: U4.6 (CTRL); also elsewhere on the board
/LoRa RF/RFI_N: C30.1, L6.2; also elsewhere on the board
/LoRa RF/RFI_P: C29.1, L6.1; also elsewhere on the board
/LoRa RF/RFO_HP: C22.2, L2.1, L3.1; also elsewhere on the board
unnamed: C22.1, C23.1, C24.1, L3.2
unnamed: C23.2, L4.1
unnamed: C26.2, C27.1, L5.1
unnamed: C28.1, J6.1 (In), L5.2
unnamed: C29.2, U4.3 (RF1)
unnamed: C25.1, L4.2, U4.1 (RF2)
unnamed: C26.1, U4.5 (RFIN)
VR_PA: C21.1, L2.2; also elsewhere on the board

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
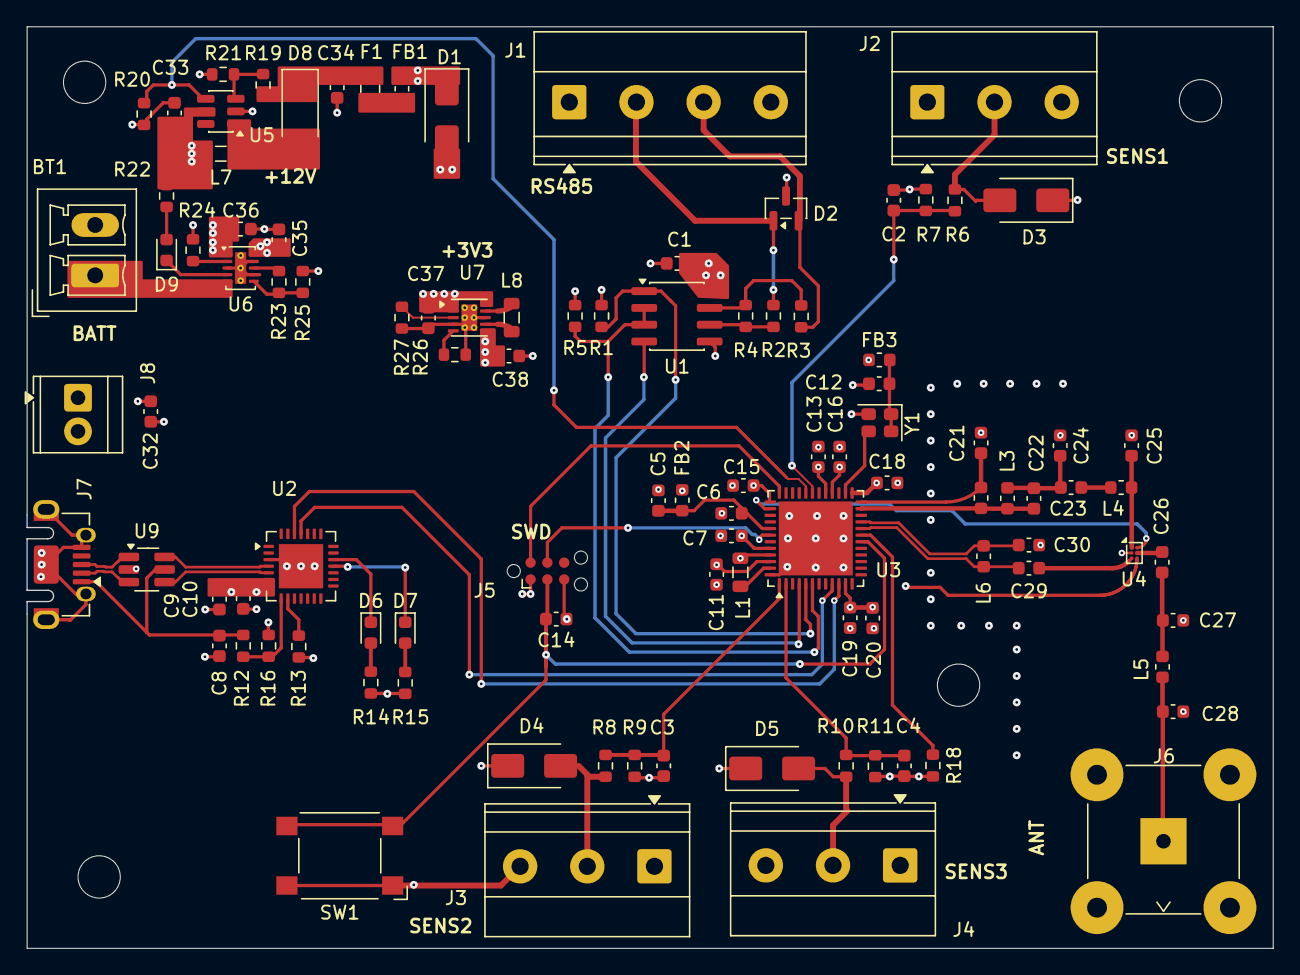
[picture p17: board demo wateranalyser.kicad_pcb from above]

Board: 4 copper layers, 94.2 x 69.7 mm, 102 parts (0 on the bottom side), 67 nets.

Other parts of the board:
R26: 16k2; R_0603_1608Metric

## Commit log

2026-08-20 modified project structure
    [LoRa RF.kicad_sch, MCU.kicad_sch, Power.kicad_sch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]
2026-08-20 removed old files
    [LoRa RF.kicad_sch, MCU.kicad_sch, Power.kicad_sch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]
2026-08-20 title block update
    [LoRa RF.kicad_sch, MCU.kicad_sch, Power.kicad_sch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]
2026-08-20 adjustment to the power section
    [LoRa RF.kicad_sch, MCU.kicad_sch, Power.kicad_sch]
2026-08-20 final hardware V1
    [MCU.kicad_sch, Power.kicad_sch, analog.kicad_sch]
